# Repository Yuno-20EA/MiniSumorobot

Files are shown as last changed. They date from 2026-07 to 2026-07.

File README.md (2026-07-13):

<div align="center">

# ⚡ MiniSumoRobot

**A compact, autonomous sumo robot built for competitive combat**





[]()

</div>

---

## Overview

MiniSumoRobot is a fully autonomous mini sumo robot designed for competitive sumo battles. The robot uses ultrasonic sensors to detect opponents and deploys a state-machine-driven attack strategy — all within a compact 3D-printed chassis manufactured with precision STL files.

The project spans the complete engineering cycle: **mechanical design → electronics → firmware → testing.**

---

## Gallery

### Robot Frame — Design Sketches

> *Hand-drawn sketches of each structural component*

<table>
  <tr>
    <td align="center">
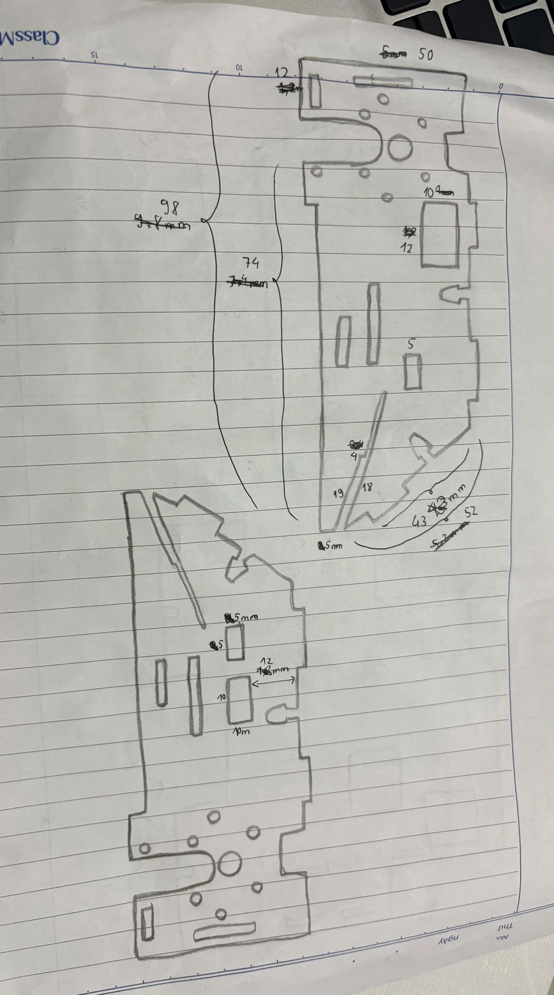
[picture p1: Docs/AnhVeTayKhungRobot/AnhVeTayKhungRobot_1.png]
      <br/>
      <sub>View 1</sub>
    </td>
    <td align="center">
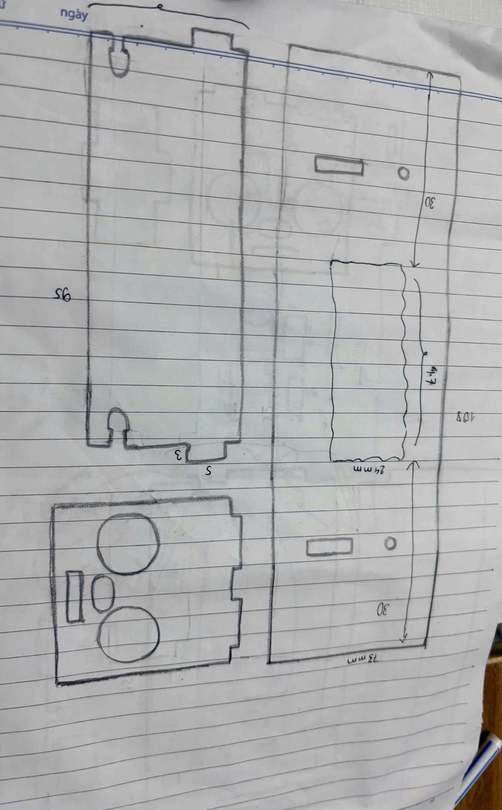
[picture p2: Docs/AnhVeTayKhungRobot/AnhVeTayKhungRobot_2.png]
      <br/>
      <sub>View 2</sub>
    </td>
    <td align="center">
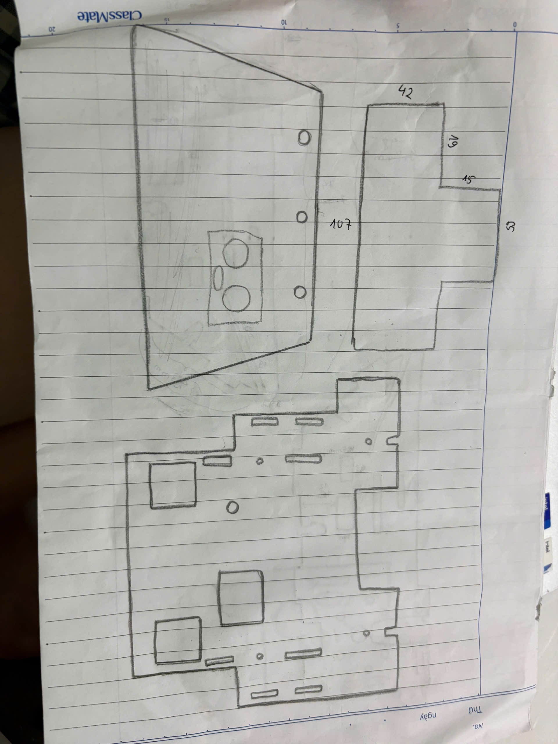
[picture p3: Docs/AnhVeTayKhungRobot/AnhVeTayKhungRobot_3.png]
      <br/>
      <sub>View 3</sub>
    </td>
    <td align="center">
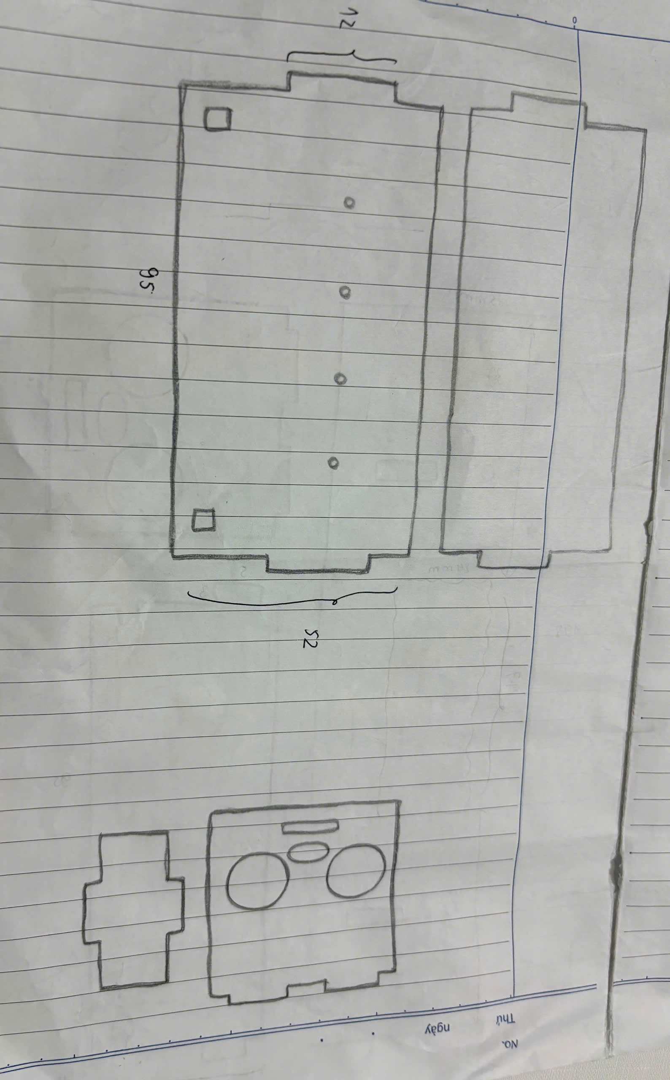
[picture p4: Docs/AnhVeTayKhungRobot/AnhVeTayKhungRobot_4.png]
      <br/>
      <sub>View 4</sub>
    </td>
  </tr>
</table>

### Real-World Photos

> *The completed robot as assembled*

<table>
  <tr>
    <td align="center">
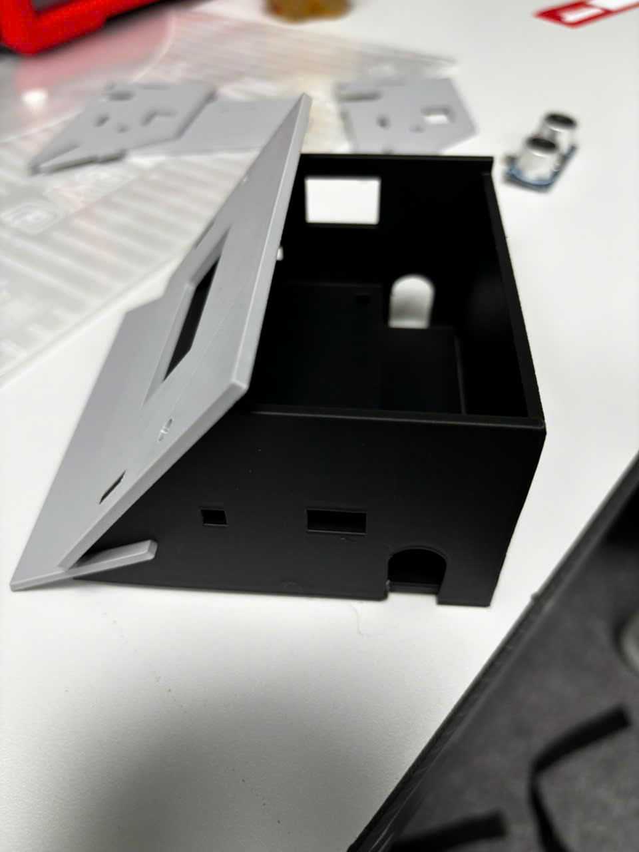
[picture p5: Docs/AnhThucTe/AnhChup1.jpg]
      <br/>
      <sub>Photo 1</sub>
    </td>
    <td align="center">
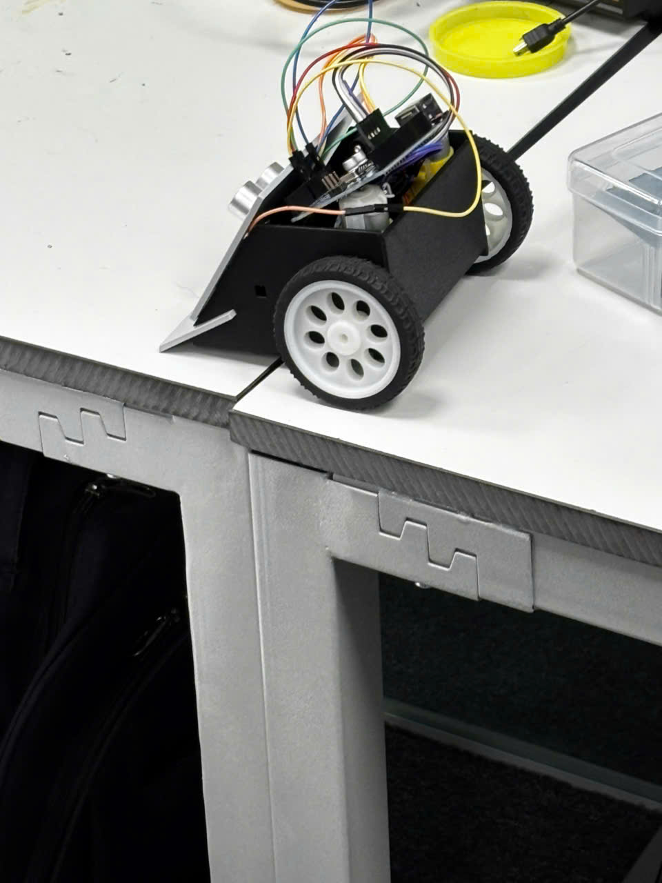
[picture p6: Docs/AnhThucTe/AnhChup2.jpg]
      <br/>
      <sub>Photo 2</sub>
    </td>
    <td align="center">
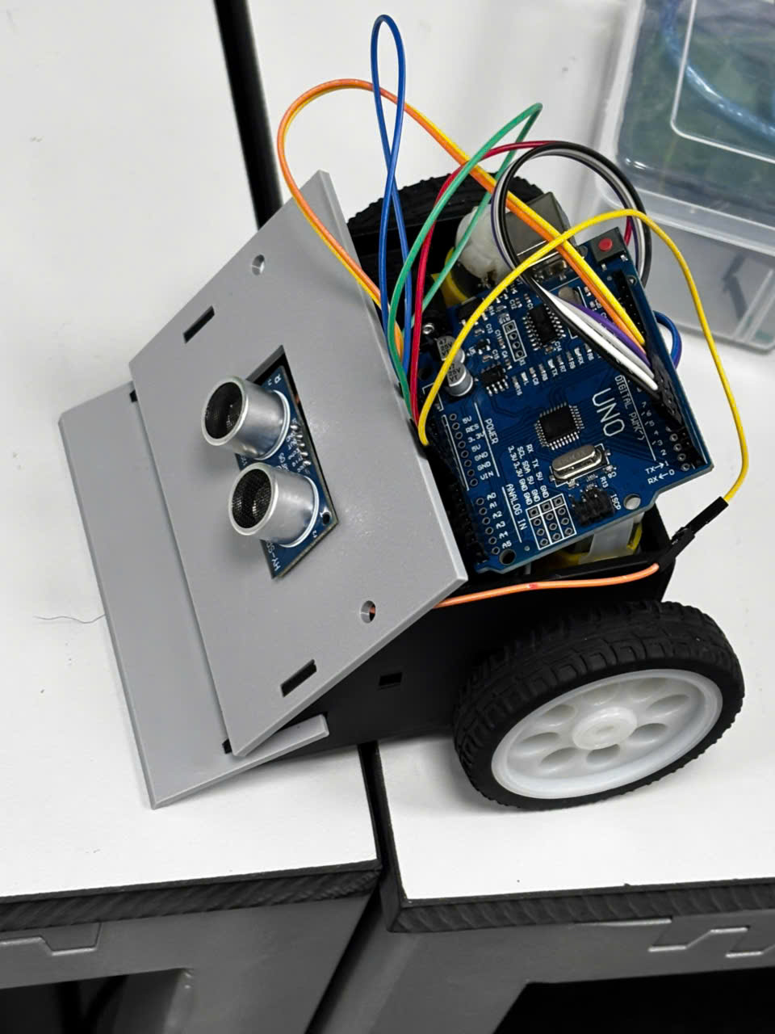
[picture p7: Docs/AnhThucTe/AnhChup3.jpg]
      <br/>
      <sub>Photo 3</sub>
    </td>
  </tr>
</table>

---

## Workflow

> *From concept to competition — the full development process*

### Development Pipeline

```
+--------------+     +--------------+     +--------------+     +--------------+
|  Mechanical  |---->|  Electronics |---->|   Firmware   |---->|   Testing    |
|   Design     |     |   Design     |     | Development  |     |  & Combat    |
+--------------+     +--------------+     +--------------+     +--------------+
  3D modeling          Schematic &           Arduino C++          Arena trials
  STL printing         Wiring layout         State machine         Optimization
```

### Workflow Images

> 📌 *Replace each placeholder below with your actual workflow process photos*

| Step | Description |
|:----|:---|
| 1 | Mechanical design & 3D modeling in CAD |
| 2 | PCB schematic & wiring layout |
| 3 | Firmware flashing & serial debugging |
| 4 | Assembly, integration & combat testing |

---

## Architecture

```
MiniSumoRobot/
│
├── Firmware/
│   └── SrcCodeSumo_Final/
│       └── SrcCodeSumo_Final.ino     # Main Arduino sketch
│
├── Hardware/
│   └── So_Do_Mach_Dien/
│       ├── So_Do_Dau_Day_FinalCheck.fzz   # Fritzing wiring diagram
│       └── Anh_Minh_Hoa_So_Do_Day.png     # Wiring illustration
│
├── Mechanical/
│   ├── Khung_robot_finalcheck.stl         # Full chassis STL
│   ├── MiniRobotComponets/                # Individual part STLs
│   │   ├── Mat_Truoc.stl                  # Front face
│   │   ├── Mat_Ben1.stl                   # Side panel 1
│   │   ├── Mat_Ben2.stl                   # Side panel 2
│   │   ├── Mat_Chua_Dong_Co.stl           # Motor mount
│   │   ├── Mat_Chua_ViDieuKhien.stl       # Controller mount
│   │   ├── Mat_Day.stl                    # Bottom plate
│   │   └── Mat_Phang_Luoi.stl             # Blade panel
│   └── Anh_Chup_CacMatLinhKien/          # Component renders
│
└── Docs/
    ├── AnhThucTe/                         # Real-world photos
    ├── AnhVeTayKhungRobot/                # Hand-drawn sketches
    └── BÁO CÁO KỸ THUẬT CỦA SUMO ROBOT.docx
```

---

## Hardware

### Bill of Materials

| Component | Model / Spec | Qty | Role |
|:---|:---|:---:|:-----|
| Microcontroller | Arduino Nano | 1 | Main control unit |
| Ultrasonic Sensor | HC-SR04 | 3 | Enemy detection — Front / Left / Right |
| DC Motor | N20 Gear Motor | 2 | Drive wheels |
| Motor Driver | L298N / L293D | 1 | PWM motor control |
| Power Supply | Li-Po / 9V Battery | 1 | Power source |
| Chassis | 3D Printed PLA | — | Custom-designed enclosure |
| Wheels | Rubber-grip | 2 | Traction |

### Wiring Diagram

<div align="center">
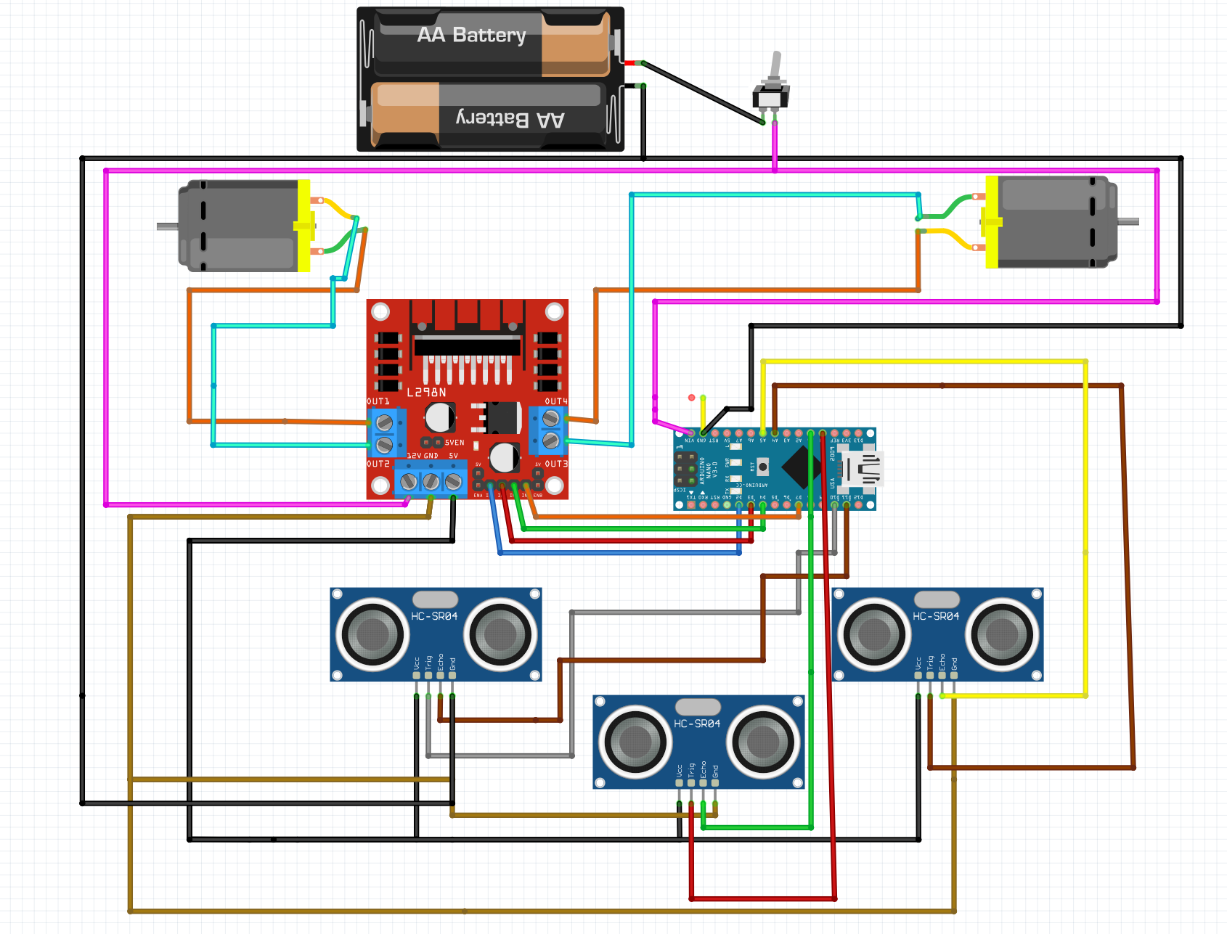
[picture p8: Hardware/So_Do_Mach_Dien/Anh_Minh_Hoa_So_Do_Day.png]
  
  <br/>
  <sub><i>Full wiring schematic — generated with Fritzing</i></sub>
</div>

### Pin Mapping

| Pin | Signal | Direction |
|:---:|:---|:---:|
| D2 | Motor A — IN1 (INA) | OUT |
| D3 | Motor A — IN2 (INB) | OUT |
| D4 | Motor B — IN1 (INC) | OUT |
| D5 | Motor B — IN2 (IND) | OUT |
| A0 | Ultrasonic Front — TRIG | OUT |
| A1 | Ultrasonic Front — ECHO | IN |
| A4 | Ultrasonic Right — TRIG | OUT |
| A5 | Ultrasonic Right — ECHO | IN |
| D10 | Ultrasonic Left — TRIG | OUT |
| D11 | Ultrasonic Left — ECHO | IN |

---

## Mechanical Design

The chassis is fully 3D-printed using PLA filament. All STL files are provided for direct reproduction.

### Component Breakdown

| Part | File | Description |
|:-----|:-----|:---|
| Front Face | `Mat_Truoc.stl` | Holds front ultrasonic sensor |
| Side Panel 1 | `Mat_Ben1.stl` | Structural left wall |
| Side Panel 2 | `Mat_Ben2.stl` | Structural right wall |
| Motor Mount | `Mat_Chua_Dong_Co.stl` | Motor bracket |
| Controller Mount | `Mat_Chua_ViDieuKhien.stl` | Arduino Nano holder |
| Bottom Plate | `Mat_Day.stl` | Base floor of chassis |
| Blade Panel | `Mat_Phang_Luoi.stl` | Low-profile front pusher |
| Full Assembly | `Khung_robot_finalcheck.stl` | Complete chassis |

### 3D Renders

<table>
  <tr>
    <td align="center">
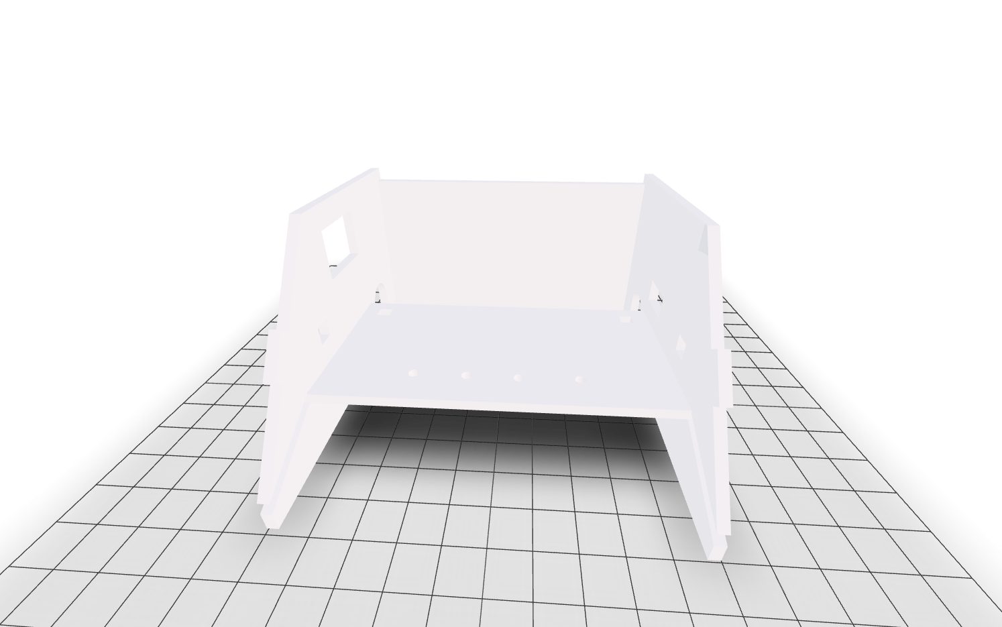
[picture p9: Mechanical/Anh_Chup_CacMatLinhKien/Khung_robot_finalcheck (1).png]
      <br/>
      <sub>Full Assembly</sub>
    </td>
    <td align="center">
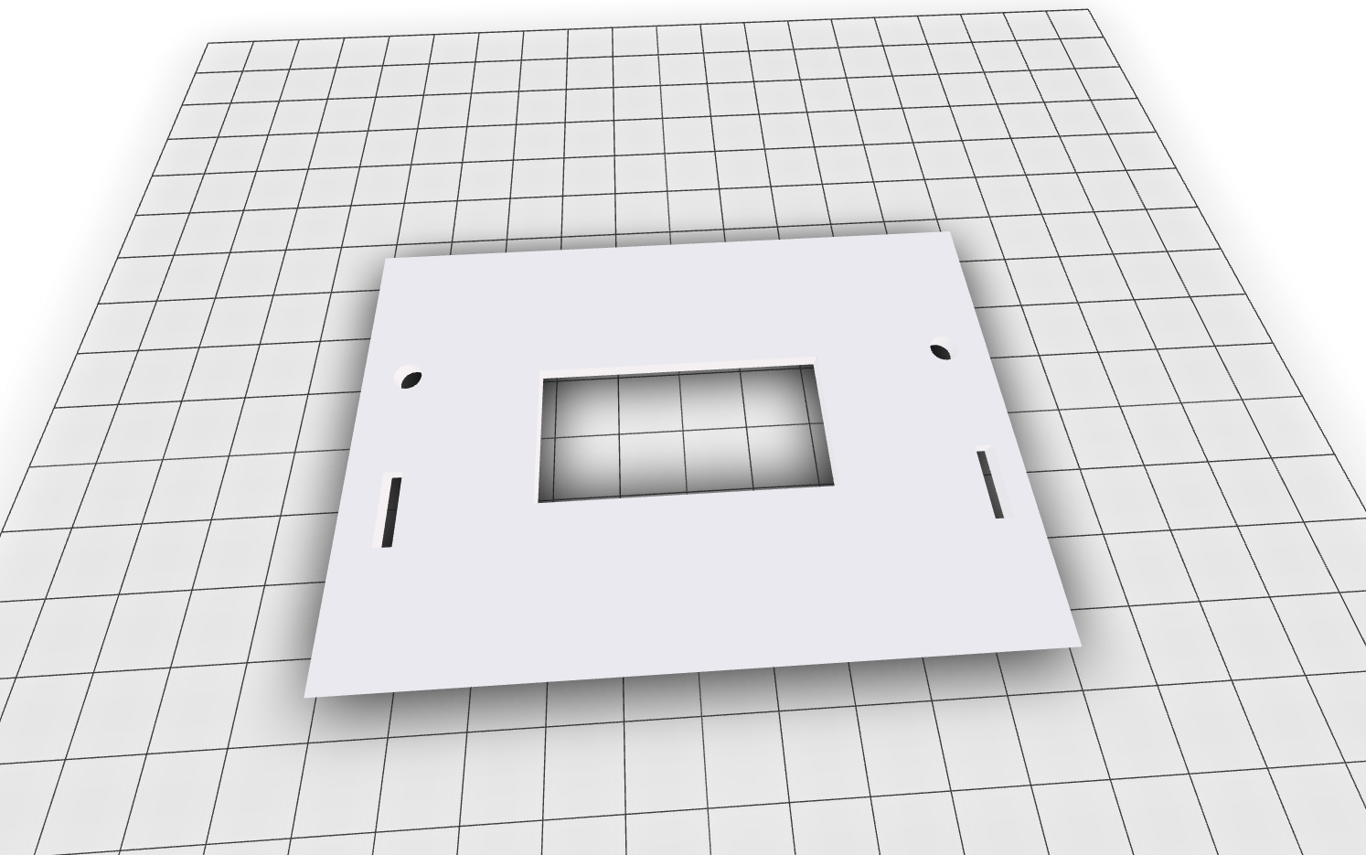
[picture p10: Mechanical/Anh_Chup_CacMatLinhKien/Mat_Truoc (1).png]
      <br/>
      <sub>Front Face</sub>
    </td>
    <td align="center">
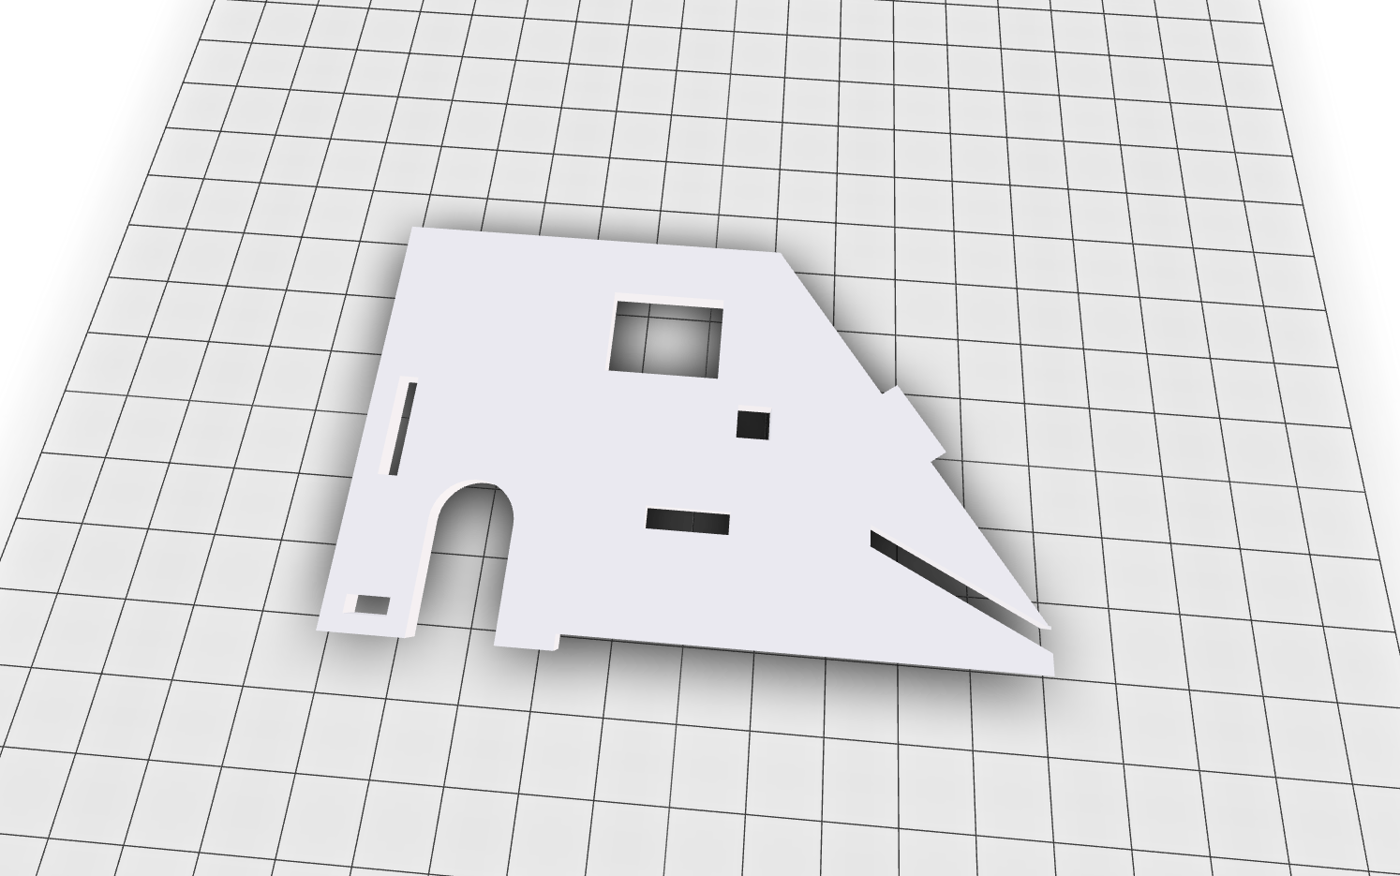
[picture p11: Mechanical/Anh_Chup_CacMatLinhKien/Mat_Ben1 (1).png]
      <br/>
      <sub>Side Panel 1</sub>
    </td>
    <td align="center">
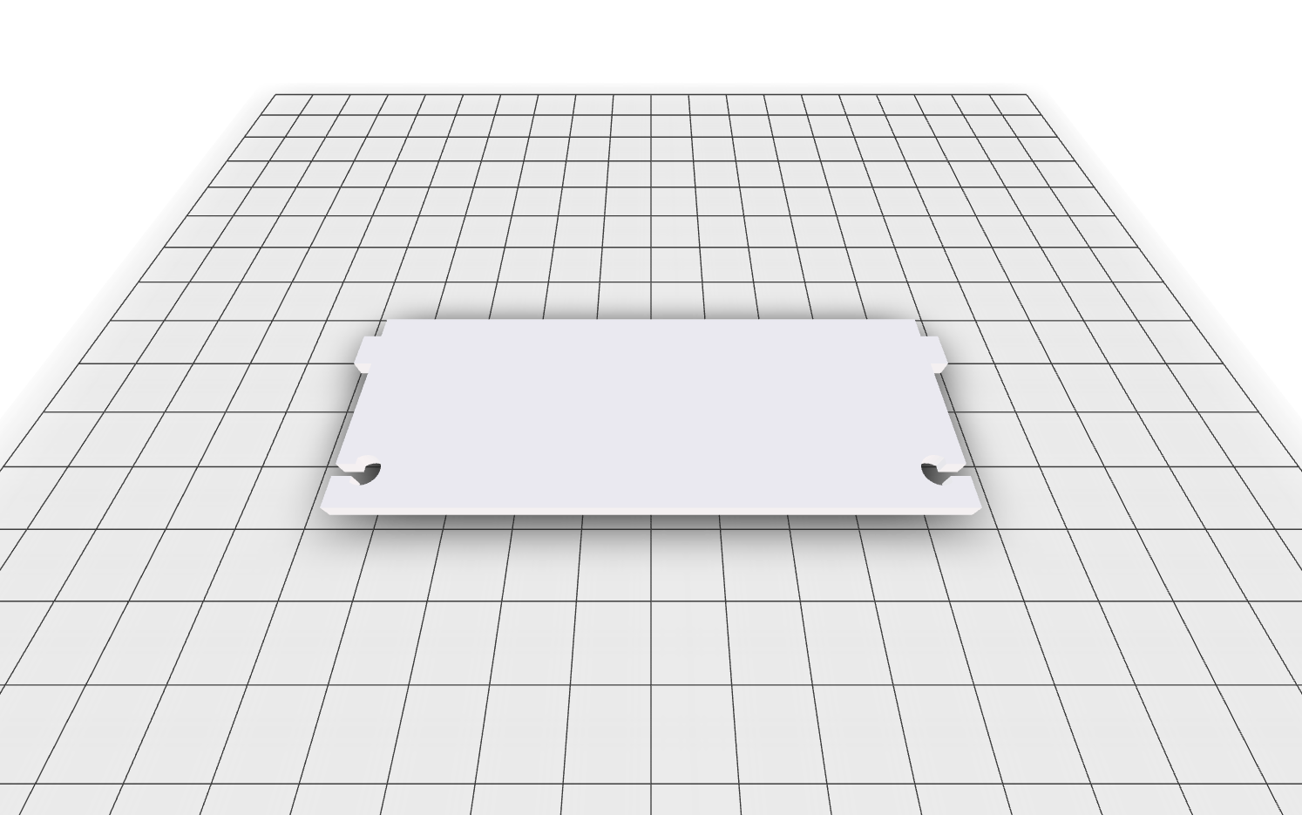
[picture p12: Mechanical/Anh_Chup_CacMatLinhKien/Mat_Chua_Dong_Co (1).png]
      <br/>
      <sub>Motor Mount</sub>
    </td>
  </tr>
</table>

---

## Firmware

### Logic Overview

The firmware is written in C++ for Arduino and uses a **non-blocking state machine** to manage sensor polling and motor control simultaneously — zero `delay()` calls.

```
Boot → 5-second countdown → Combat mode active

Loop:
  updateSensors() ──► poll 1 of 3 sensors every 30ms (round-robin)
        │
        ▼
  runAttackStateMachine()
        │
        ├── enemyFront  →  MOVE_FORWARD  (charge)
        ├── enemyRight  →  MOVE_RIGHT  →  MOVE_FORWARD
        ├── enemyLeft   →  MOVE_LEFT   →  MOVE_FORWARD
        └── no target   →  MOVE_LEFT   (scanning sweep)
```

### State Machine Phases

| Phase | Description |
|:---|:---|
| `AP_DECIDE` | Evaluate sensor flags and choose next move |
| `AP_COAST` | Brief motor-off interval before direction change |
| `AP_WAIT_TURN` | Execute turn, then transition to forward thrust |
| `AP_WAIT_FORWARD` | Execute forward charge |

### Key Parameters

```cpp
TIME_FORWARD  = 100 ms   // Duration of forward thrust
TIME_LEFT     = 180 ms   // Duration of left turn
TIME_RIGHT    = 180 ms   // Duration of right turn
COAST_MS      = 20  ms   // Motor coast between direction changes
MAX_DISTANCE  = 50  cm   // Ultrasonic detection range
PING_INTERVAL = 30  ms   // Round-robin sensor poll interval
```

---

## Getting Started

### Prerequisites

- [Arduino IDE](https://www.arduino.cc/en/software) `≥ 1.8` or [PlatformIO](https://platformio.org/)
- Arduino Library: [`NewPing`](https://bitbucket.org/teckel12/arduino-new-ping/wiki/Home) by Tim Eckel

### Flash the Firmware

```bash
# 1. Clone the repository
git clone https://github.com/Yuno-20EA/MiniSumorobot.git
cd MiniSumorobot

# 2. Open in Arduino IDE
# File → Open → Firmware/SrcCodeSumo_Final/SrcCodeSumo_Final.ino

# 3. Install dependency via Library Manager
# Tools → Manage Libraries → Search "NewPing" → Install

# 4. Configure board
# Tools → Board → Arduino Nano
# Tools → Processor → ATmega328P (Old Bootloader)

# 5. Upload to board
```

### Print the Chassis

1. Open any `.stl` file from `Mechanical/MiniRobotComponets/`  
   or use the full assembly: `Mechanical/Khung_robot_finalcheck.stl`
2. Recommended slicer settings:

| Setting | Value |
|:---|:---|
| Material | PLA |
| Layer height | 0.2 mm |
| Infill | 30 – 40% |
| Supports | Enabled |
| Nozzle temperature | 200 – 210 °C |

---

## Combat Strategy

The robot operates **fully autonomously** after a **5-second activation delay** (standard sumo rule compliance).

```
Priority order (high → low):

  1. Enemy detected FRONT  →  charge forward immediately
  2. Enemy detected RIGHT  →  turn right → charge forward
  3. Enemy detected LEFT   →  turn left  → charge forward
  4. No enemy detected     →  rotate left (scanning sweep)
```

> A **2-consecutive-reading confirmation** filter is applied to each sensor before committing to an attack — preventing false positives from sensor noise.

---

## Documentation

| Document | Location | Description |
|:---|:---|:---|
| Technical Report | [`Docs/`](Docs/) | Full engineering report (Vietnamese) |
| Wiring Schematic | [`Hardware/So_Do_Mach_Dien/`](Hardware/So_Do_Mach_Dien/) | Fritzing source & PNG export |
| 3D Models | [`Mechanical/MiniRobotComponets/`](Mechanical/MiniRobotComponets/) | All STL component files |
| 3D Renders | [`Mechanical/Anh_Chup_CacMatLinhKien/`](Mechanical/Anh_Chup_CacMatLinhKien/) | Render images per component |
| Real Photos | [`Docs/AnhThucTe/`](Docs/AnhThucTe/) | Physical build photos |
| Design Sketches | [`Docs/AnhVeTayKhungRobot/`](Docs/AnhVeTayKhungRobot/) | Hand-drawn frame sketches |

---

## License

This project is licensed under the **MIT License** — see [`LICENSE`](LICENSE) for details.

---

<div align="center">

*Made with precision — MiniSumoRobot · 2025*

</div>

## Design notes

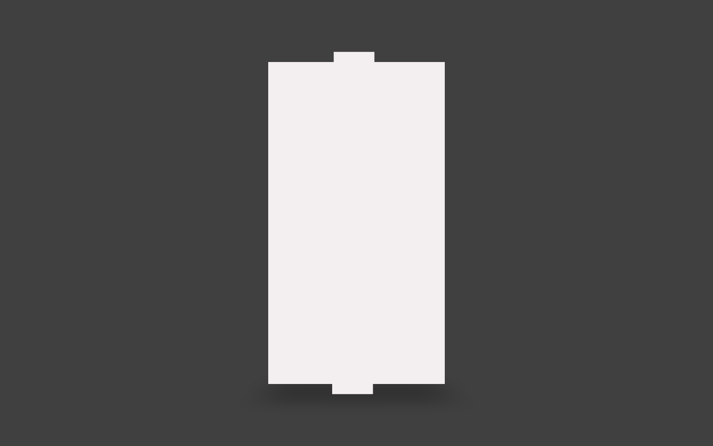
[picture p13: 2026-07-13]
MiniSumoRobot/Mechanical/Anh_Chup_CacMatLinhKien/Mat_Day.png

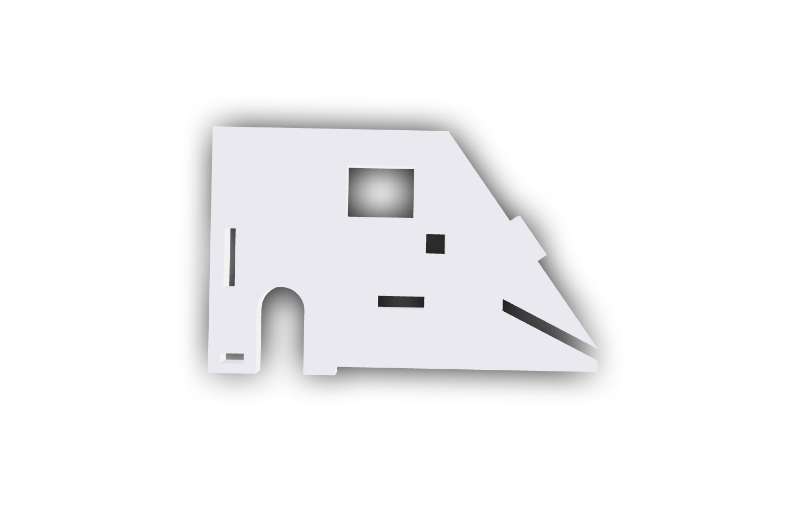
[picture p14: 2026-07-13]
Mechanical/Anh_Chup_CacMatLinhKien/Mat_Ben1.png

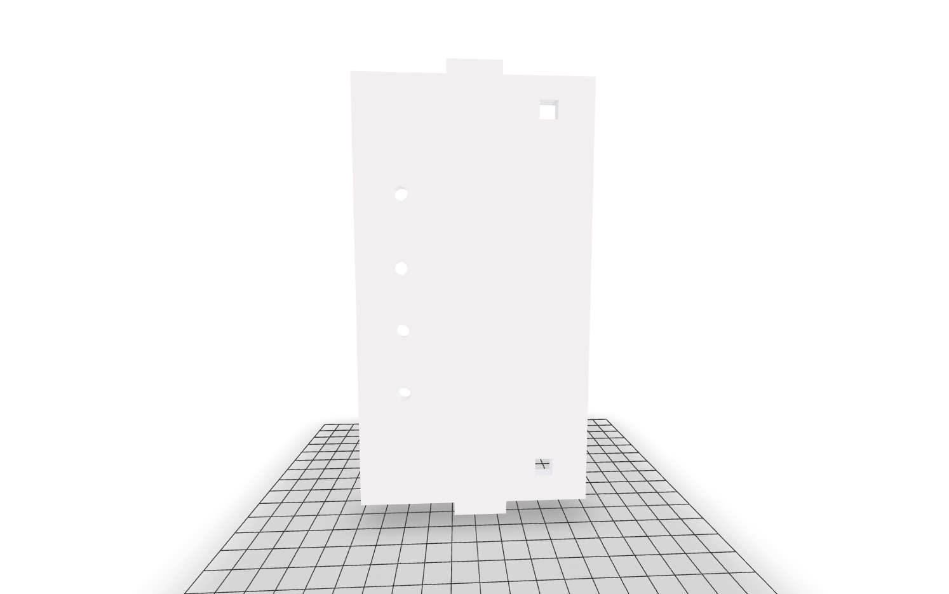
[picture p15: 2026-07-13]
Mechanical/Anh_Chup_CacMatLinhKien/Mat_Chua_ViDieuKhien (1).png

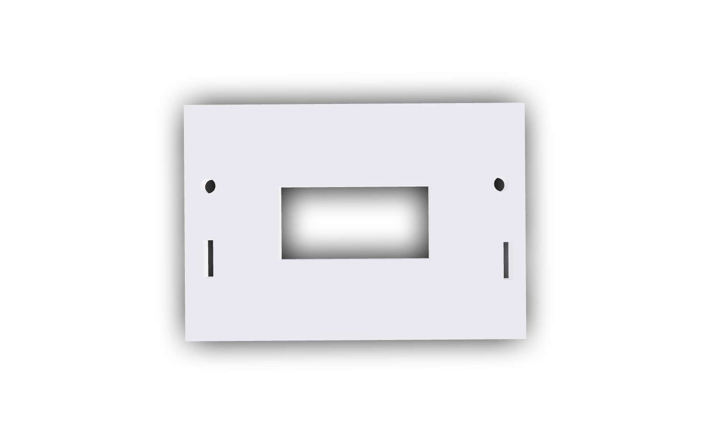
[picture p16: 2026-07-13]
MiniSumoRobot/Mechanical/Anh_Chup_CacMatLinhKien/Mat_Truoc.png

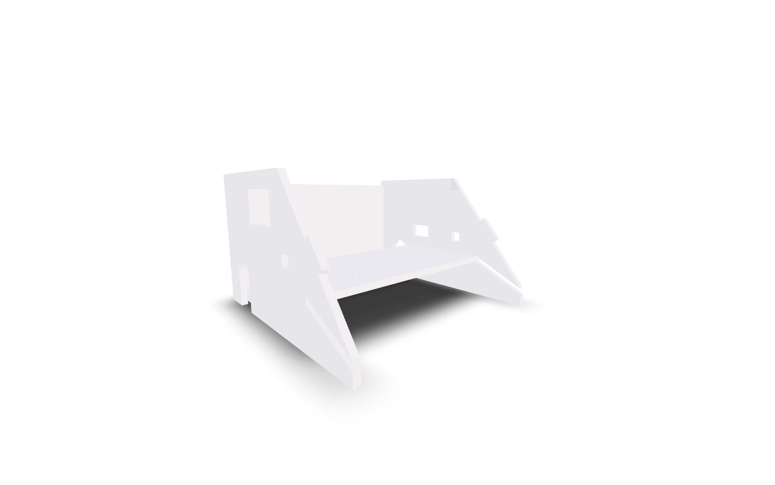
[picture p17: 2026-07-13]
MiniSumoRobot/Mechanical/Anh_Chup_CacMatLinhKien/Khung_robot_finalcheck.png

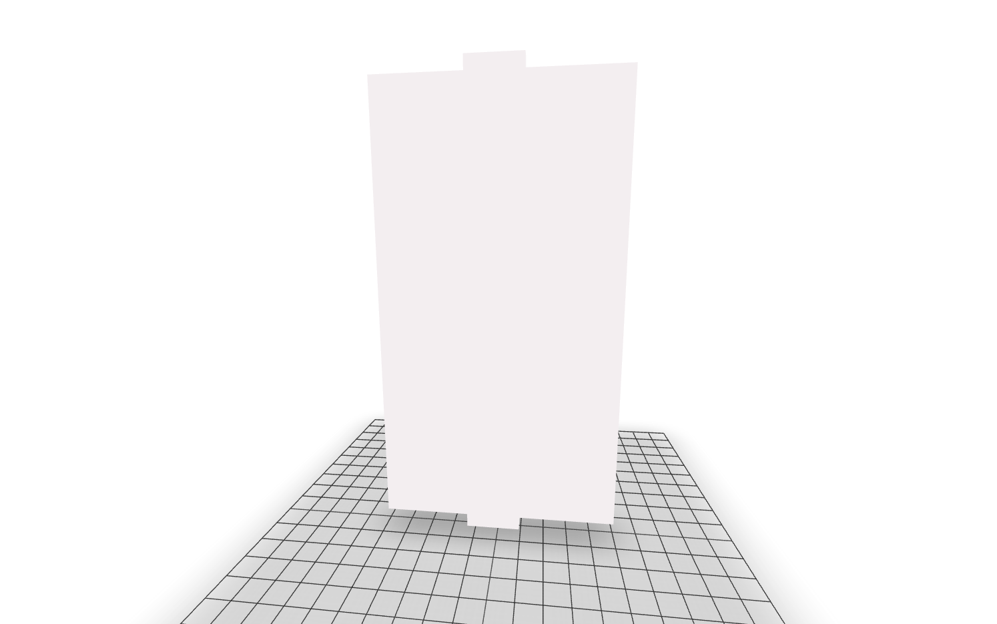
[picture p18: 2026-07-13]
MiniSumoRobot/Mechanical/Anh_Chup_CacMatLinhKien/Mat_Day (1).png

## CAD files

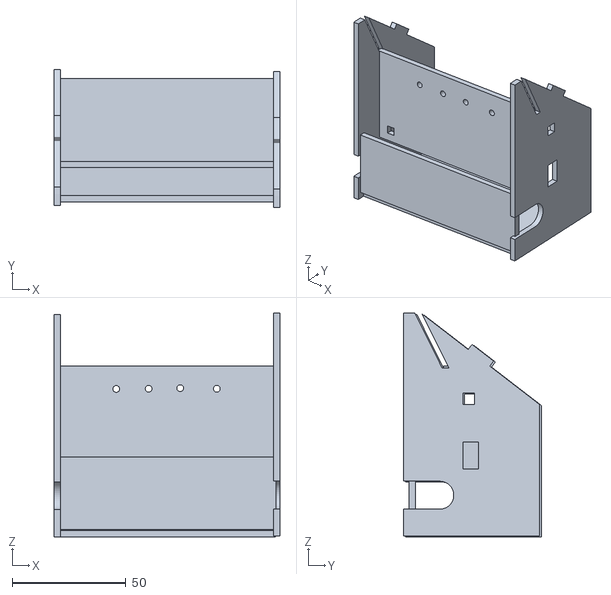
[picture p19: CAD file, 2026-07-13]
Mechanical/Khung_robot_finalcheck.stl
99.5 x 60.8 x 98.5

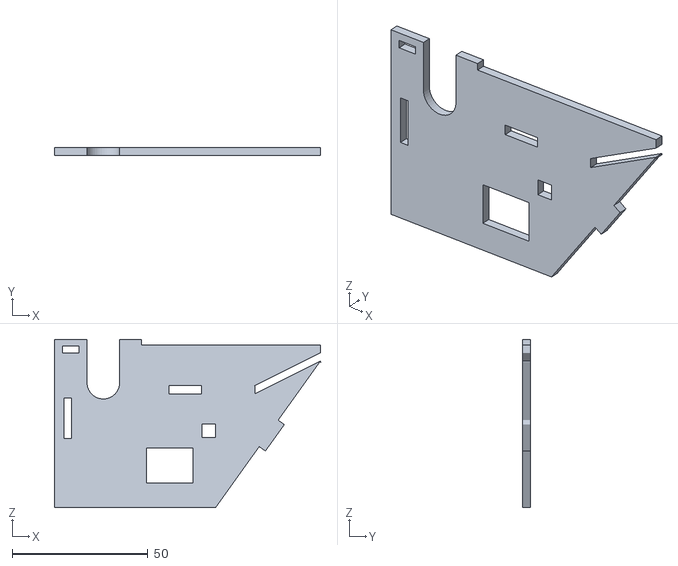
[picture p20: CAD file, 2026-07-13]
Mechanical/MiniRobotComponets/Mat_Ben1.stl
98.0 x 2.80 x 62.1

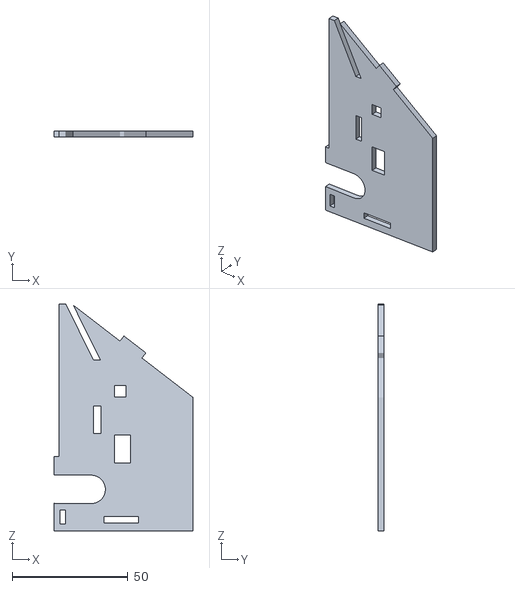
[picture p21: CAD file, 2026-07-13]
MiniSumoRobot/Mechanical/MiniRobotComponets/Mat_Ben2.stl
60.0 x 2.80 x 98.2

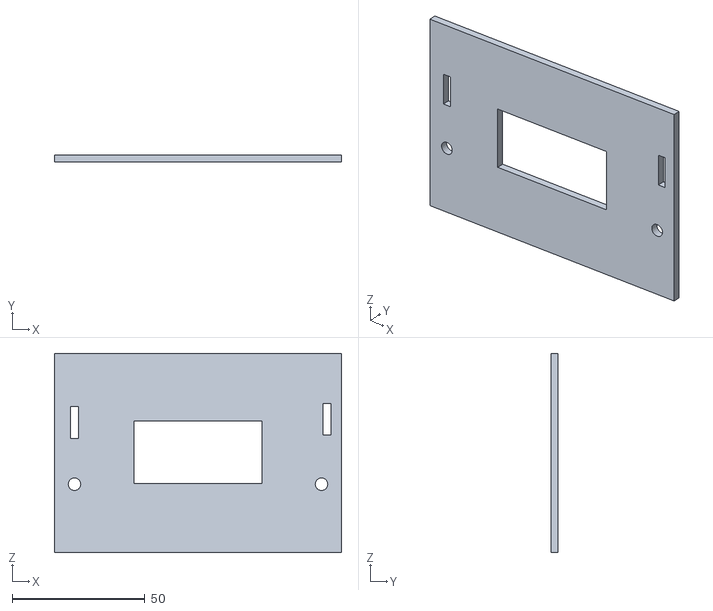
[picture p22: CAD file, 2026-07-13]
MiniSumoRobot/Mechanical/MiniRobotComponets/Mat_Truoc.stl
108.0 x 2.80 x 75.0

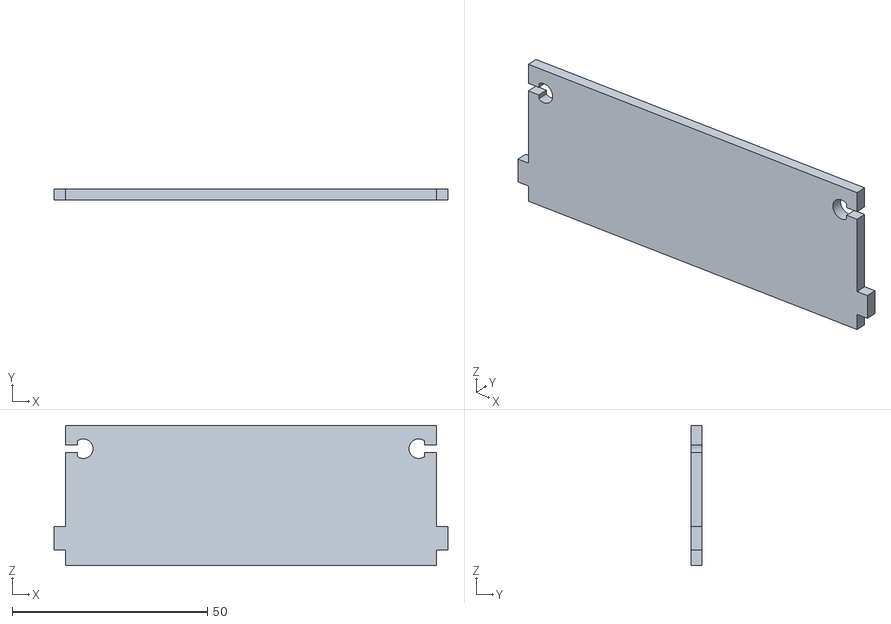
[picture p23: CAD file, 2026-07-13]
Mechanical/MiniRobotComponets/Mat_Chua_Dong_Co.stl
101.0 x 2.80 x 36.0

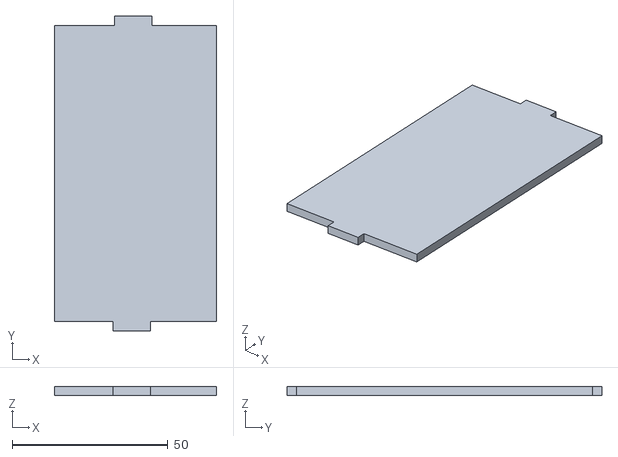
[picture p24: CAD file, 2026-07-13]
MiniSumoRobot/Mechanical/MiniRobotComponets/Mat_Day.stl
52.0 x 101.0 x 2.80

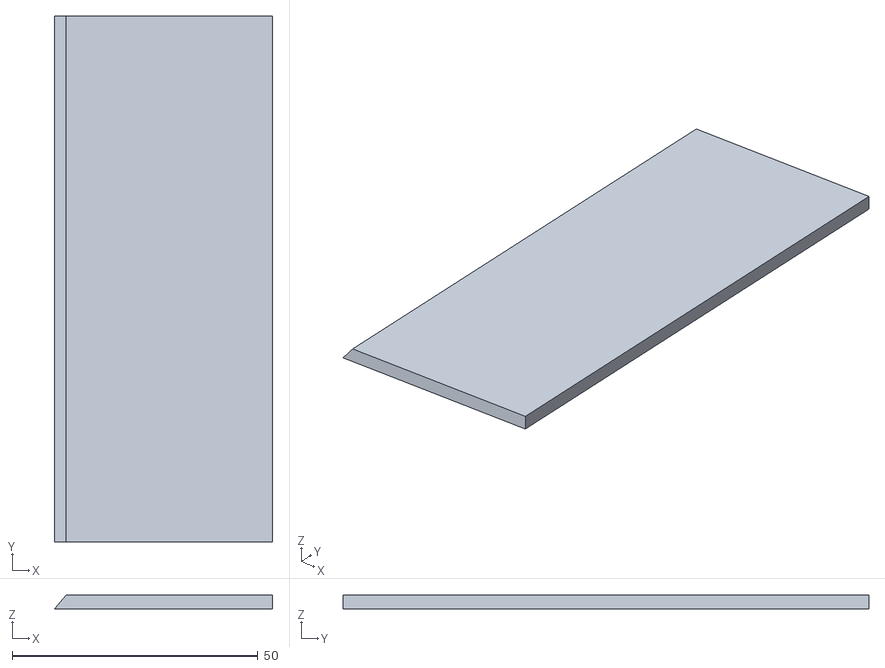
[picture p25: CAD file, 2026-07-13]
Mechanical/MiniRobotComponets/Mat_Phang_Luoi.stl
44.3 x 107.0 x 2.80

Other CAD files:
Mechanical/MiniRobotComponets/Mat_Chua_ViDieuKhien.stl
MiniSumoRobot/Mechanical/MiniRobotComponets/Mat_Chua_ViDieuKhien.stl

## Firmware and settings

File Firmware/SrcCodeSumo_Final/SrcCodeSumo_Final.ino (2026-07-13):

#include <NewPing.h>
#include <Arduino.h>
const unsigned long TIME_FORWARD = 100;
const unsigned long TIME_LEFT    = 180;
const unsigned long TIME_RIGHT   = 180;

const unsigned long COAST_MS = 20;

const int INA = 2, INB = 3;  
const int INC = 4, IND = 5; 

const int TRIG_FRONT = A0, ECHO_FRONT = A1;
const int TRIG_RIGHT = A4, ECHO_RIGHT = A5;
const int TRIG_LEFT  = 10, ECHO_LEFT  = 11;
const int MAX_DISTANCE = 50;

NewPing sonarFront(TRIG_FRONT, ECHO_FRONT, MAX_DISTANCE);
NewPing sonarRight(TRIG_RIGHT, ECHO_RIGHT, MAX_DISTANCE);
NewPing sonarLeft (TRIG_LEFT,  ECHO_LEFT,  MAX_DISTANCE);

int  distFront = 0, distRight = 0, distLeft = 0;
int  cntFront = 0,  cntRight = 0,  cntLeft = 0;
bool enemyFront = false, enemyRight = false, enemyLeft = false;
bool isTimeUp = false;

const unsigned long PING_INTERVAL_MS = 30;
unsigned long lastPingTime = 0;
uint8_t sensorIndex = 0;  

enum ActionPhase { AP_DECIDE, AP_COAST, AP_WAIT_TURN, AP_WAIT_FORWARD };
enum Move { MOVE_FORWARD, MOVE_LEFT, MOVE_RIGHT };

ActionPhase actionPhase = AP_DECIDE;
unsigned long phaseEndTime = 0;
Move currentMove = MOVE_FORWARD;        
Move pendingMove = MOVE_FORWARD;     
unsigned long pendingDuration = 0;
ActionPhase pendingResultPhase = AP_DECIDE;

void setup() {
  pinMode(INA, OUTPUT); pinMode(INB, OUTPUT);
  pinMode(INC, OUTPUT); pinMode(IND, LOW);
}
//  ĐỘNG CƠ 
void forward() {
  digitalWrite(INA, HIGH); digitalWrite(INB, LOW);
  digitalWrite(INC, HIGH); digitalWrite(IND, LOW);
}
void left() {
  digitalWrite(INA, LOW);  digitalWrite(INB, HIGH);
  digitalWrite(INC, HIGH); digitalWrite(IND, LOW);
}
void right() {
  digitalWrite(INA, HIGH); digitalWrite(INB, LOW);
  digitalWrite(INC, LOW);  digitalWrite(IND, HIGH);
}
void stopMotors() {
  digitalWrite(INA, LOW); digitalWrite(INB, LOW);
  digitalWrite(INC, LOW); digitalWrite(IND, LOW);
}

void applyMove(Move m) {
  switch (m) {
    case MOVE_FORWARD: forward(); break;
    case MOVE_LEFT:    left();    break;
    case MOVE_RIGHT:   right();   break;
  }
}

void updateFlag(int dist, int &counter, bool &flag) {
  if (dist > 0 && dist < MAX_DISTANCE) counter++; else counter = 0;
  flag = (counter >= 2);
}

void updateSensors() {

  
  if (actionPhase == AP_COAST) return;
  if (millis() - lastPingTime < PING_INTERVAL_MS) return;
  lastPingTime = millis();
  switch (sensorIndex) {
    case 0: distFront = sonarFront.ping_cm(); updateFlag(distFront, cntFront, enemyFront); break;
    case 1: distRight = sonarRight.ping_cm(); updateFlag(distRight, cntRight, enemyRight); break;
    case 2: distLeft  = sonarLeft.ping_cm();  updateFlag(distLeft,  cntLeft,  enemyLeft);  break;
  }
  sensorIndex = (sensorIndex + 1) % 3;
}
void queueMove(Move m, unsigned long duration, ActionPhase resultPhase) {
  if (m == currentMove) {
    actionPhase = resultPhase;
    phaseEndTime = millis() + duration;
    return;
  }
  stopMotors();
  pendingMove = m;
  pendingDuration = duration;
  pendingResultPhase = resultPhase;
  currentMove = m;
  actionPhase = AP_COAST;
  phaseEndTime = millis() + COAST_MS;
}

void runAttackStateMachine() {
  if (millis() < phaseEndTime) return;
  if (actionPhase == AP_COAST) {
    applyMove(pendingMove);
    actionPhase = pendingResultPhase;
    phaseEndTime = millis() + pendingDuration;
    return;
  }
  if (actionPhase == AP_WAIT_TURN) { 
    queueMove(MOVE_FORWARD, TIME_FORWARD, AP_WAIT_FORWARD);
    return;
  }
  if (enemyFront) {
    queueMove(MOVE_FORWARD, TIME_FORWARD, AP_WAIT_FORWARD);
  } else if (enemyRight) {
    queueMove(MOVE_RIGHT, TIME_RIGHT, AP_WAIT_TURN);
  } else if (enemyLeft) {
    queueMove(MOVE_LEFT, TIME_LEFT, AP_WAIT_TURN);
  } else {
    queueMove(MOVE_LEFT, 0, AP_DECIDE);   
  }
}
void loop() {
  if (millis() > 5000) isTimeUp = true;

  updateSensors();
  if (!isTimeUp) return;

  runAttackStateMachine(); 
}

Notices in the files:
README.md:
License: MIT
